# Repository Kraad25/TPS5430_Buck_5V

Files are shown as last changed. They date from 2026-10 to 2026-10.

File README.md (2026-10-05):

# TPS5430_Buck_5V

A 12V-to-5V synchronous buck converter built around the TI TPS54308, designed in
KiCad.

Schematic and component values derived directly from the TPS54308 datasheet.

## Specs

- **Controller:** TPS54308 (4.5V-28V input, 3A synchronous buck converter, SOT-23-6)
- **Input:** 12V DC via barrel jack
- **Output:** 5V, 3A via 2-pin header
- **Switching frequency:** 350kHz (fixed, internal)
- **Layers:** 2-layer
- **Note:** Found and corrected a unit typo in the datasheet's Table 7-2 (C6
  listed as µF, confirmed via TI's own body text and the compensation equation
  to actually be pF)

## PCB Design

### Schematic

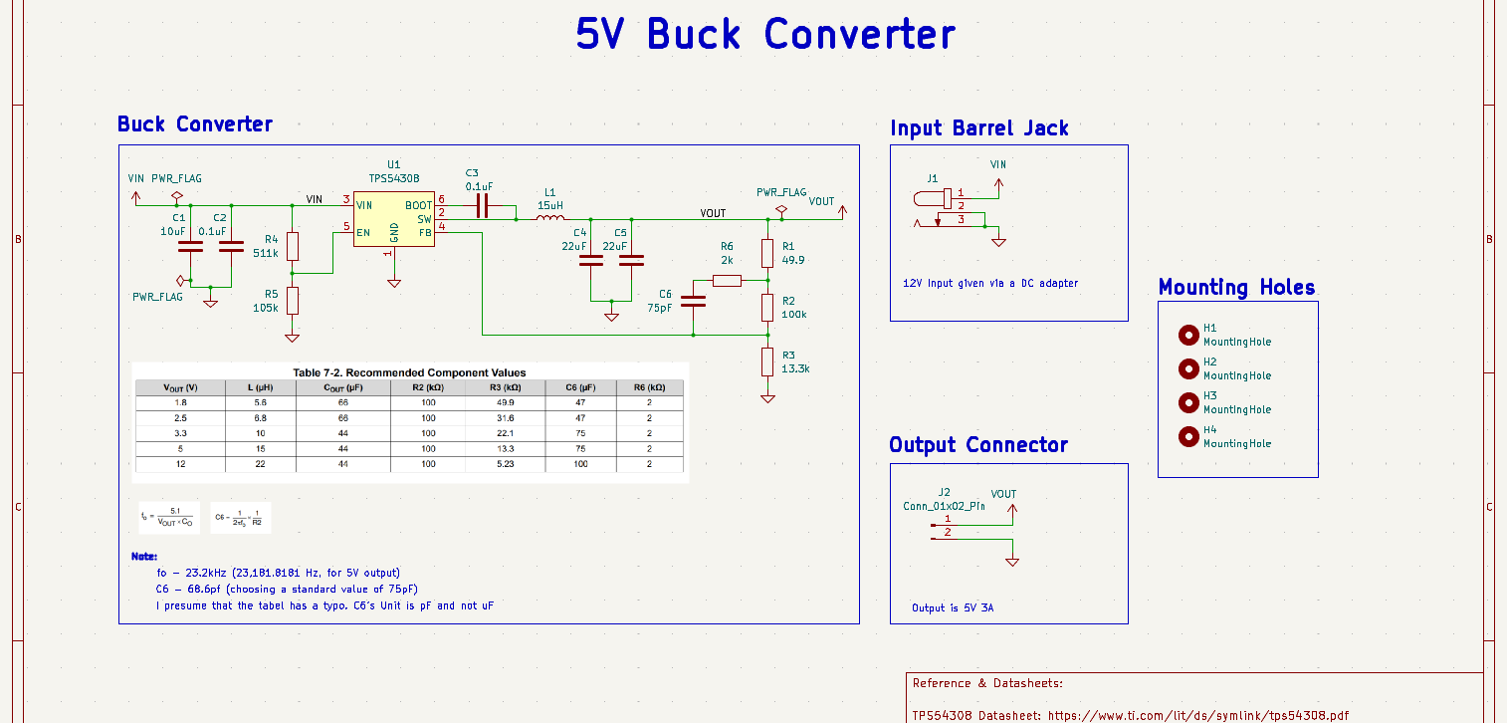
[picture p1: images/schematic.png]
Schematic


### PCB Layout

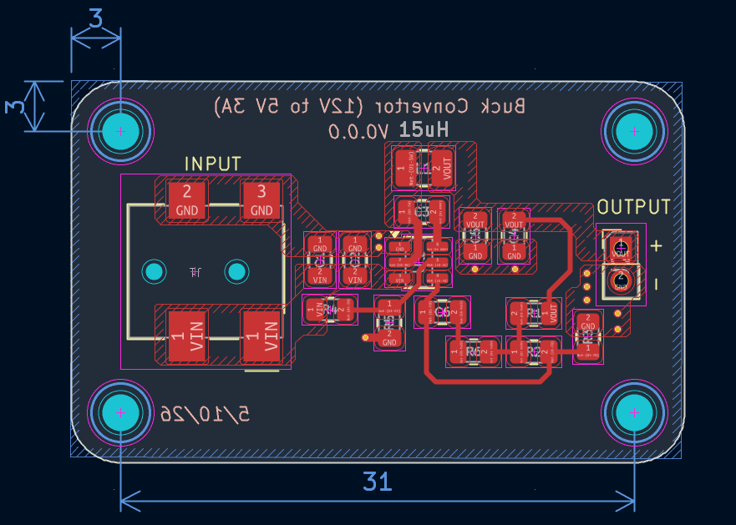
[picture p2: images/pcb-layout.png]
PCB Layout


### 3D Renders

<p float="left">
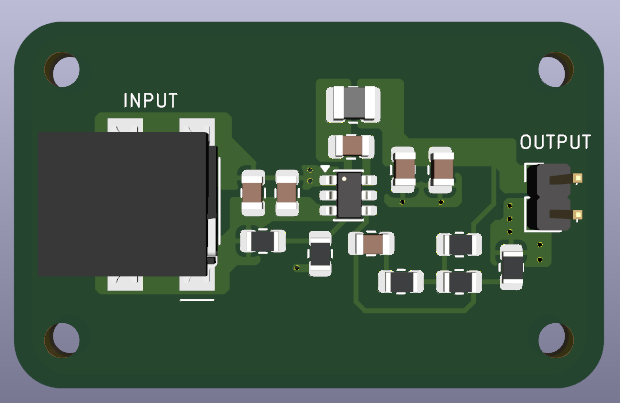
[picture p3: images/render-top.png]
PCB 3D render - top view
  
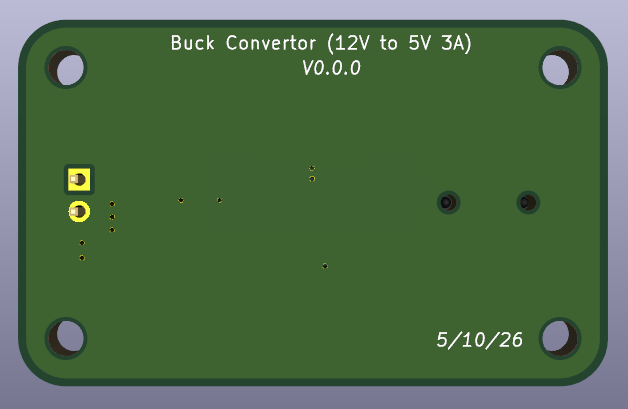
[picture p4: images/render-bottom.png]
PCB 3D render - bottom view
  
</p>

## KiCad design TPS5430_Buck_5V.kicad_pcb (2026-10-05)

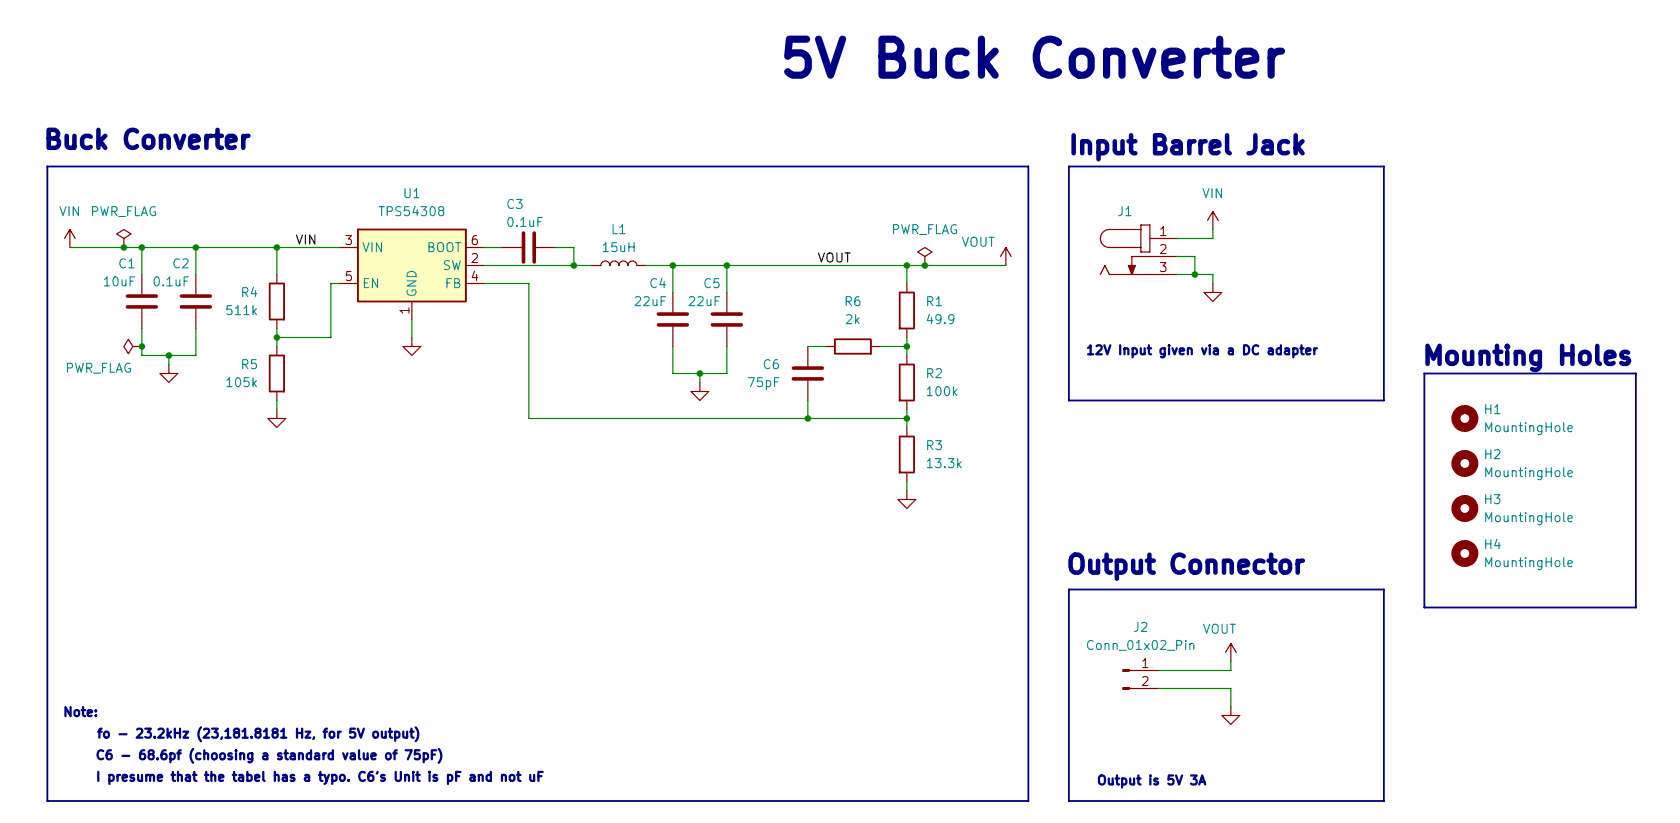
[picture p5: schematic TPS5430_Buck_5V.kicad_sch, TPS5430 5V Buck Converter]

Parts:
C1: 10uF; C_0805_2012Metric
C2, C3: 0.1uF; C_0805_2012Metric
C4, C5: 22uF; C_0805_2012Metric
C6: 75pF; C_0805_2012Metric
H1, H2, H3, H4: MountingHole; MountingHole_2.2mm_M2_ISO7380
J1: 694103107102; J_Wurth_WR-DC_694103107102; Working Voltage (V (DC)) 24; Part Number 694103107102
J2: Conn_01x02_Pin; PinHeader_1x02_P2.00mm_Vertical
L1: 15uH; L_1008_2520Metric
R1: 49.9; R_0805_2012Metric
R2: 100k; R_0805_2012Metric
R3: 13.3k; R_0805_2012Metric
R4: 511k; R_0805_2012Metric
R5: 105k; R_0805_2012Metric
R6: 2k; R_0805_2012Metric
U1: TPS54308; SOT-23-6

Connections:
GND: C1.1, C2.1, C4.1, C5.1, J1.2, J1.3, J2.2, R3.2, R5.2, U1.1 (GND)
unnamed: C6.2, R6.1
unnamed: R1.2, R2.1, R6.2
unnamed: C3.2, U1.6 (BOOT)
unnamed: R4.2, R5.1, U1.5 (EN)
unnamed: C6.1, R2.2, R3.1, U1.4 (FB)
unnamed: C3.1, L1.1, U1.2 (SW)
VIN: C1.2, C2.2, J1.1, R4.1, U1.3 (VIN)
VOUT: C4.2, C5.2, J2.1, L1.2, R1.1

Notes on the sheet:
Mounting Holes
Buck Converter
Output Connector
I presume that the tabel has a typo. C6's Unit is pF and not uF
12V Input given via a DC adapter
fo - 23.2kHz (23,181.8181 Hz, for 5V output)
Note:
C6 - 68.6pf (choosing a standard value of 75pF)
5V Buck Converter
Input Barrel Jack
Output is 5V 3A

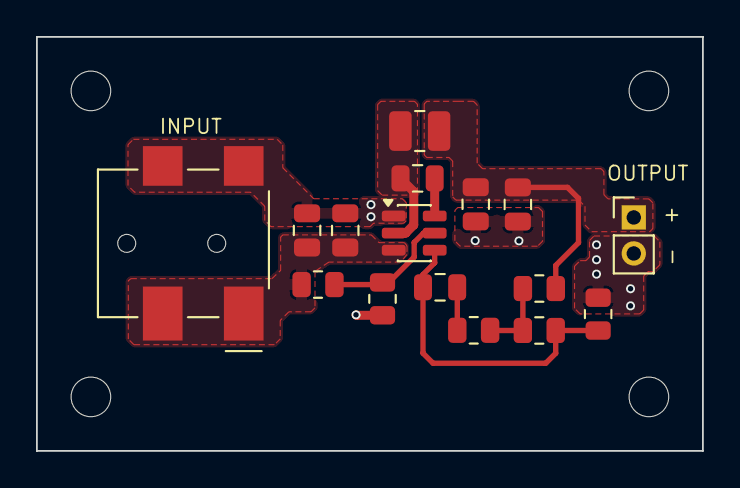
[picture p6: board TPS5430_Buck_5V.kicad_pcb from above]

Board: 2 copper layers, 37.0 x 23.0 mm, 20 parts (0 on the bottom side), 9 nets.

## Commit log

2026-09-22 add TPS54308 Buck Converter Schematic
    [TPS5430_Buck_5V.kicad_pcb, TPS5430_Buck_5V.kicad_sch]
2026-10-02 add barrel jack symbol,footprint and 3d model and rough placement
    [TPS5430_Buck_5V.kicad_pcb, TPS5430_Buck_5V.kicad_sch]
2026-10-03 redo component placement and finish routing
    [TPS5430_Buck_5V.kicad_pcb, TPS5430_Buck_5V.kicad_sch]
2026-10-03 add texts in silkscreen
    [TPS5430_Buck_5V.kicad_pcb]
2026-10-05 add thermal reliefs to avoid tombstoning
    [TPS5430_Buck_5V.kicad_pcb]
2026-10-05 moved the schematic down
    [TPS5430_Buck_5V.kicad_sch]
